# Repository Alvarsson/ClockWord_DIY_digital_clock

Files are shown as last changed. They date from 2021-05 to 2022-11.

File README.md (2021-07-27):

# ClockWork_DIY_digital_clock
Code for homemade digital clock. 

# Effects to add
"Circle" + line in the middle
Fill in/out on number change
"Circle" wave

# Important notes
The KiCad design doesn't have a voltage divider for the TX pin of the ESP8266. If the arduino isn't talking to the ESP8266 properly, make sure that the input voltage to the Arduino isn't too high.

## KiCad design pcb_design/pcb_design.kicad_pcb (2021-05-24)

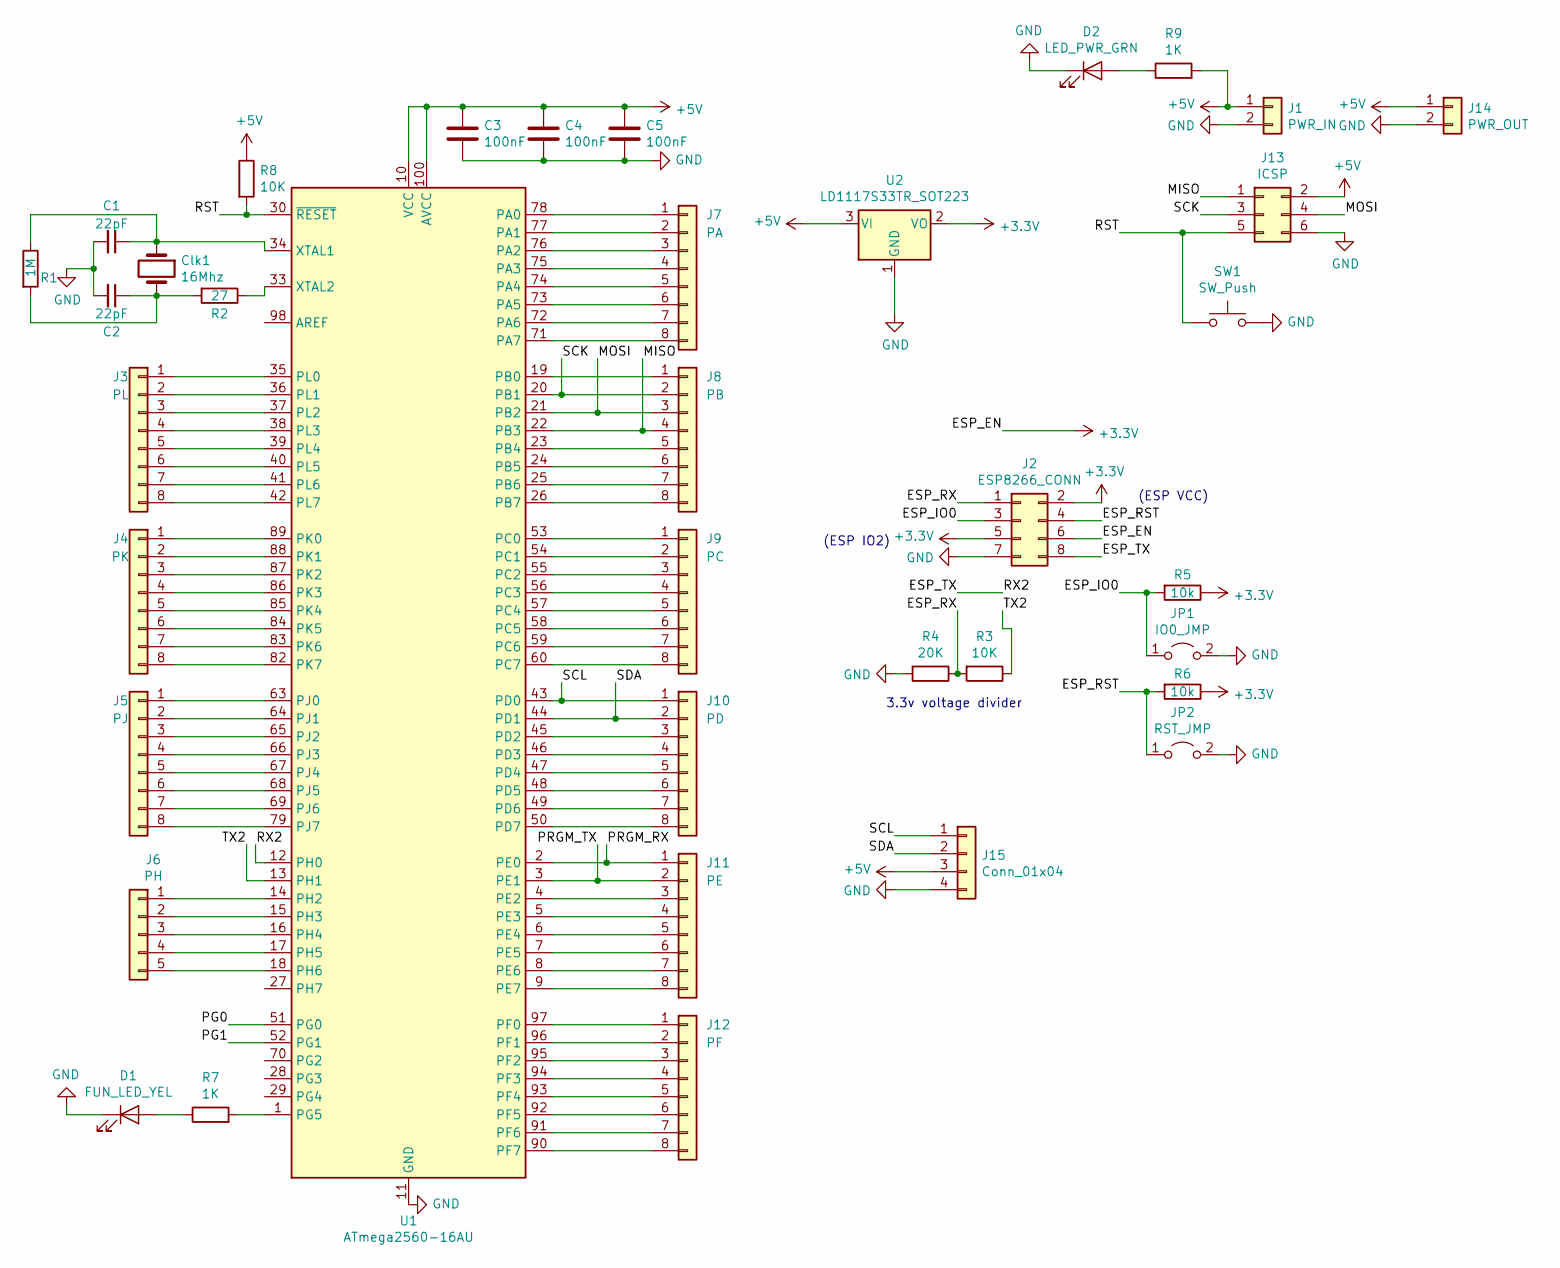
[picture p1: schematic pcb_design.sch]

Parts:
C1, C2: 22pF; C_0603_1608Metric
C3, C4, C5: 100nF; C_0603_1608Metric
Clk1: 16Mhz; Crystal_HC49-4H_Vertical
D1: FUN_LED_YEL; LED_0603_1608Metric
D2: LED_PWR_GRN; LED_0603_1608Metric
J1: PWR_IN; PinHeader_1x02_P2.54mm_Vertical
J2: ESP8266_CONN; PinHeader_2x04_P2.54mm_Vertical
J3: PL; PinHeader_1x08_P2.54mm_Vertical
J4: PK; PinHeader_1x08_P2.54mm_Vertical
J5: PJ; PinHeader_1x08_P2.54mm_Vertical
J6: PH; PinHeader_1x05_P2.54mm_Vertical
J7: PA; PinHeader_1x08_P2.54mm_Vertical
J8: PB; PinHeader_1x08_P2.54mm_Vertical
J9: PC; PinHeader_1x08_P2.54mm_Vertical
J10: PD; PinHeader_1x08_P2.54mm_Vertical
J11: PE; PinHeader_1x08_P2.54mm_Vertical
J12: PF; PinHeader_1x08_P2.54mm_Vertical
J13: ICSP; PinHeader_2x03_P2.54mm_Vertical
J14: PWR_OUT; PinHeader_1x02_P2.54mm_Vertical
J15: Conn_01x04; PinSocket_1x04_P2.54mm_Vertical
JP1: IO0_JMP; PinHeader_1x02_P2.54mm_Vertical
JP2: RST_JMP; PinHeader_1x02_P2.54mm_Vertical
R1: 1M; R_0603_1608Metric
R2: 27; R_0603_1608Metric
R3, R8: 10K; R_0603_1608Metric
R4: 20K; R_0603_1608Metric
R5, R6: 10k; R_0603_1608Metric
R7, R9: 1K; R_0603_1608Metric
SW1: SW_Push; SW_SPST_B3U-1000P
U1: ATmega2560-16AU; TQFP-100_14x14mm_P0.5mm
U2: LD1117S33TR_SOT223; SOT-223-3_TabPin2

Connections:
+3V3: J2.2, J2.5, J2.6, R5.1, R6.1, U2.2 (VO)
+5V: C3.1, C4.1, C5.1, J1.1, J13.2, J14.1, J15.3, R8.1, R9.2, U1.10 (VCC), U1.31 (VCC), U1.61 (VCC), U1.80 (VCC), U1.100 (AVCC), U2.3 (VI)
/ESP_IO0: J2.3, JP1.1 (A), R5.2
/ESP_RST: J2.4, JP2.1 (A), R6.2
/ESP_RX: J2.1, R3.2, R4.1
/ESP_TX: J2.8, U1.12 (PH0)
/MISO: J8.4, J13.1, U1.22 (PB3)
/MOSI: J8.3, J13.4, U1.21 (PB2)
/PG0: U1.51 (PG0)
/PG1: U1.52 (PG1)
/PRGM_RX: J11.1, U1.2 (PE0)
/PRGM_TX: J11.2, U1.3 (PE1)
/RST: J13.5, R8.2, SW1.1, U1.30 (~RESET)
/SCK: J8.2, J13.3, U1.20 (PB1)
/SCL: J10.1, J15.1, U1.43 (PD0)
/SDA: J10.2, J15.2, U1.44 (PD1)
/TX2: R3.1, U1.13 (PH1)
GND: C1.2, C2.2, C3.2, C4.2, C5.2, D1.1 (K), D2.1 (K), J1.2, J2.7, J13.6, J14.2, J15.4, JP1.2 (B), JP2.2 (B), R4.2, SW1.2, U1.11 (GND), U1.32 (GND), U1.62 (GND), U1.81 (GND), U1.99 (GND), U2.1 (GND)
unnamed: C1.1, Clk1.1, R1.1, U1.34 (XTAL1)
unnamed: C2.1, Clk1.2, R1.2, R2.2
unnamed: D1.2 (A), R7.1
unnamed: D2.2 (A), R9.1
unnamed: J3.1, U1.35 (PL0)
unnamed: J3.2, U1.36 (PL1)
unnamed: J3.3, U1.37 (PL2)
unnamed: J3.4, U1.38 (PL3)
unnamed: J3.5, U1.39 (PL4)
unnamed: J3.6, U1.40 (PL5)
unnamed: J3.7, U1.41 (PL6)
unnamed: J3.8, U1.42 (PL7)
unnamed: J4.1, U1.89 (PK0)
unnamed: J4.2, U1.88 (PK1)
unnamed: J4.3, U1.87 (PK2)
unnamed: J4.4, U1.86 (PK3)
unnamed: J4.5, U1.85 (PK4)
unnamed: J4.6, U1.84 (PK5)
unnamed: J4.7, U1.83 (PK6)
unnamed: J4.8, U1.82 (PK7)
unnamed: J5.1, U1.63 (PJ0)
unnamed: J5.2, U1.64 (PJ1)
unnamed: J5.3, U1.65 (PJ2)
unnamed: J5.4, U1.66 (PJ3)
unnamed: J5.5, U1.67 (PJ4)
unnamed: J5.6, U1.68 (PJ5)
unnamed: J5.7, U1.69 (PJ6)
unnamed: J5.8, U1.79 (PJ7)
unnamed: J6.1, U1.14 (PH2)
unnamed: J6.2, U1.15 (PH3)
unnamed: J6.3, U1.16 (PH4)
unnamed: J6.4, U1.17 (PH5)
unnamed: J6.5, U1.18 (PH6)
unnamed: J7.1, U1.78 (PA0)
unnamed: J7.2, U1.77 (PA1)
unnamed: J7.3, U1.76 (PA2)
unnamed: J7.4, U1.75 (PA3)
unnamed: J7.5, U1.74 (PA4)
unnamed: J7.6, U1.73 (PA5)
unnamed: J7.7, U1.72 (PA6)
unnamed: J7.8, U1.71 (PA7)
unnamed: J8.1, U1.19 (PB0)
unnamed: J8.5, U1.23 (PB4)
unnamed: J8.6, U1.24 (PB5)
unnamed: J8.7, U1.25 (PB6)
unnamed: J8.8, U1.26 (PB7)
unnamed: J9.1, U1.53 (PC0)
unnamed: J9.2, U1.54 (PC1)
unnamed: J9.3, U1.55 (PC2)
unnamed: J9.4, U1.56 (PC3)
unnamed: J9.5, U1.57 (PC4)
unnamed: J9.6, U1.58 (PC5)
unnamed: J9.7, U1.59 (PC6)
unnamed: J9.8, U1.60 (PC7)
unnamed: J10.3, U1.45 (PD2)
unnamed: J10.4, U1.46 (PD3)
unnamed: J10.5, U1.47 (PD4)
unnamed: J10.6, U1.48 (PD5)
unnamed: J10.7, U1.49 (PD6)
unnamed: J10.8, U1.50 (PD7)
unnamed: J11.3, U1.4 (PE2)
unnamed: J11.4, U1.5 (PE3)
unnamed: J11.5, U1.6 (PE4)
unnamed: J11.6, U1.7 (PE5)
unnamed: J11.7, U1.8 (PE6)
unnamed: J11.8, U1.9 (PE7)
unnamed: J12.1, U1.97 (PF0)
unnamed: J12.2, U1.96 (PF1)
unnamed: J12.3, U1.95 (PF2)
unnamed: J12.4, U1.94 (PF3)
unnamed: J12.5, U1.93 (PF4)
unnamed: J12.6, U1.92 (PF5)
unnamed: J12.7, U1.91 (PF6)
unnamed: J12.8, U1.90 (PF7)
unnamed: R2.1, U1.33 (XTAL2)
unnamed: R7.2, U1.1 (PG5)

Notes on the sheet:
(ESP VCC)
(ESP IO2)
3.3v voltage divider

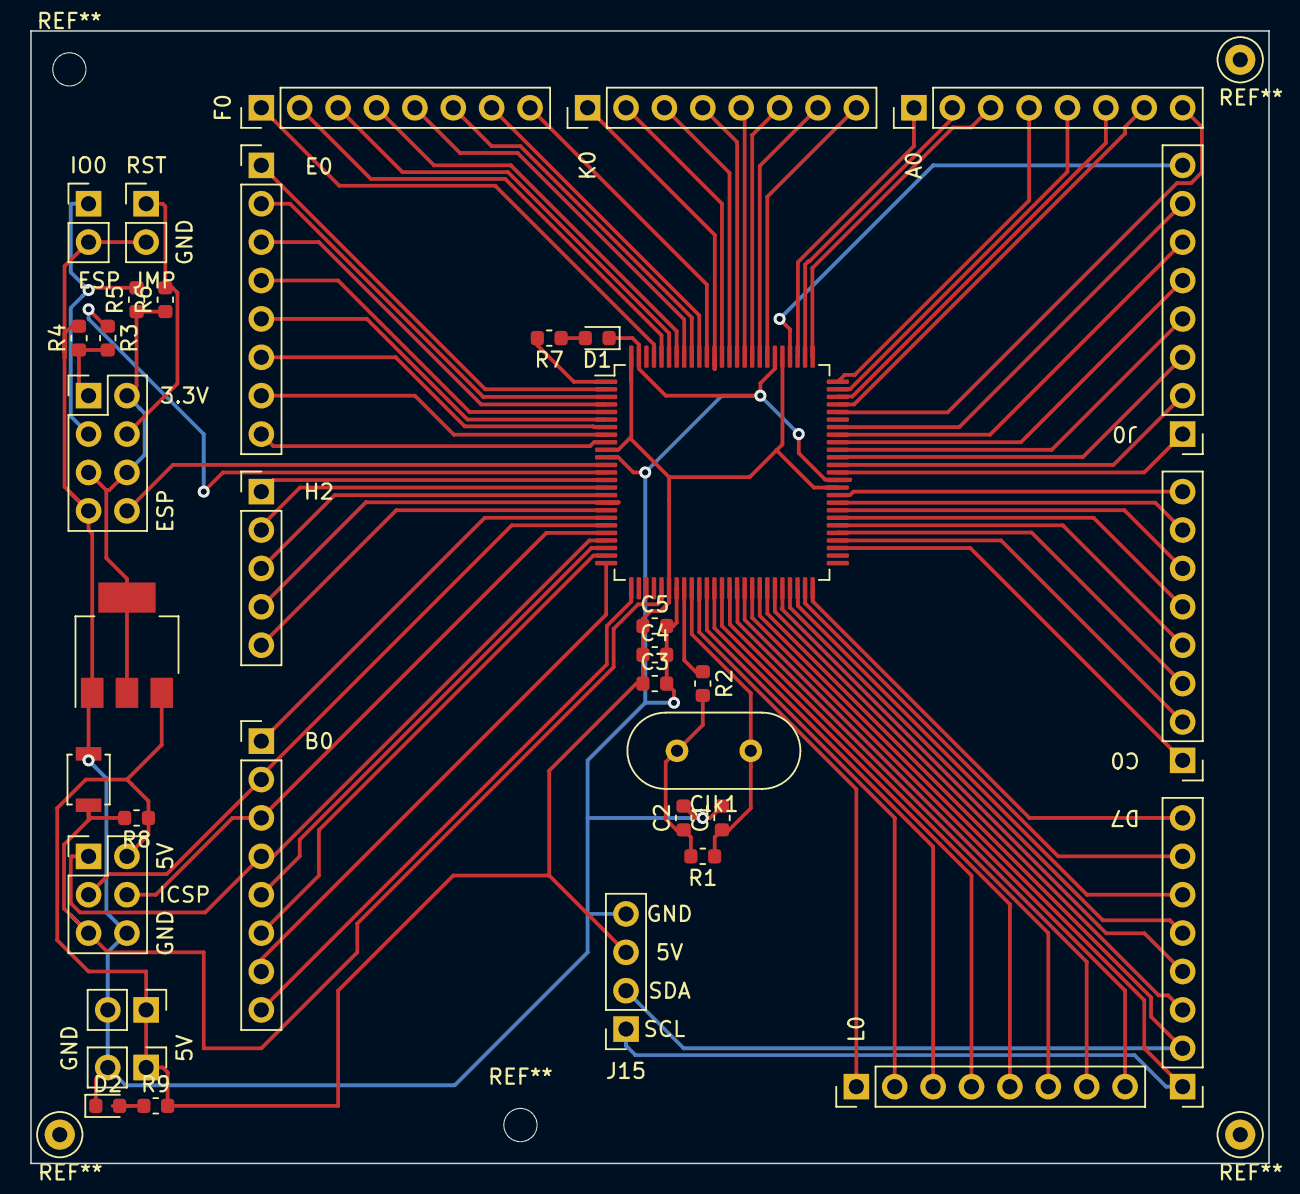
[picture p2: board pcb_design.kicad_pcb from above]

Board: 2 copper layers, 81.9 x 74.9 mm, 37 parts (0 on the bottom side), 92 nets.

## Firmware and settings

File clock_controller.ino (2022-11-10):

#include "animations.h"

#define SW_RX 6
#define SW_TX 7
#define COLOR_COUNT 4

#define BRIGHTNESS 100

CRGB wave_colors[] = {CRGB(0, BRIGHTNESS, 0), CRGB(BRIGHTNESS, 0, 0), CRGB(BRIGHTNESS, BRIGHTNESS, 0), CRGB(BRIGHTNESS, 0, BRIGHTNESS)};
rgb_wave waves[COLOR_COUNT];
clock_t clock;

uint32_t leet_start = 49020;
uint32_t leet_end = 49020 + 60;
uint32_t yes_start = 15600;
uint32_t yes_end = 15600 + 60;
uint32_t current_time_seconds = 10;

uint8_t timer_overflow_count;

// Serial and FastLED also use
// interrupts, so don't use them/call
// functions that use them from this
// interrupt handler
ISR(TIMER1_COMPA_vect) {
  TCNT0 = 0;
  timer_overflow_count++;
  if (timer_overflow_count == 250) {
    clock.dots_on = !clock.dots_on;
    current_time_seconds++;
    timer_overflow_count = 0;
  }
}

void display_time(clock_t *clock, uint32_t seconds) {
  uint32_t days = (seconds / 86400);
  uint32_t hours = (seconds % 86400) / 3600;
  uint32_t minutes = (seconds % 3600) / 60;

  disable_incorrect_segments(&clock->displays[0], numbers[hours / 10]);
  disable_incorrect_segments(&clock->displays[1], numbers[hours % 10]);
  disable_incorrect_segments(&clock->displays[2], numbers[minutes / 10]);
  disable_incorrect_segments(&clock->displays[3], numbers[minutes % 10]);

}

#define TIME_CHARS 8
#define HOURS_MSD_OFFSET 0
#define HOURS_LSD_OFFSET 1
#define MINUTES_MSD_OFFSET 3
#define MINUTES_LSD_OFFSET 4
#define SECONDS_MSD_OFFSET 6
#define SECONDS_LSD_OFFSET 7
void get_time() {
  uint32_t now = current_time_seconds;
  
  Serial3.write("AT+CIPSNTPTIME?\r\n", 18);

  int space_count = 0;
  uint32_t loop_count = 0;
  while (space_count < 3) {
    int input = Serial3.read();
    Serial.write(input);
    if (input == ' ') {
      space_count++;
    }
    loop_count++;
    if (loop_count == 400000) {
      return;
    }
  }

  uint8_t all_str[TIME_CHARS];
  Serial3.readBytes(all_str, TIME_CHARS);

  uint32_t hours = ((all_str[HOURS_MSD_OFFSET] - '0') * 10) + (all_str[HOURS_LSD_OFFSET] - '0');
  uint32_t minutes = ((all_str[MINUTES_MSD_OFFSET] - '0') * 10) + (all_str[MINUTES_LSD_OFFSET] - '0');
  uint32_t seconds = ((all_str[SECONDS_MSD_OFFSET] - '0') * 10) + (all_str[SECONDS_LSD_OFFSET] - '0');

  Serial3.readBytes(all_str, 6);

  current_time_seconds = (hours * 3600) + (minutes * 60) + seconds;

  Serial.print(current_time_seconds);

}

#undef ECHO
#ifdef ECHO
void setup() {
  Serial.begin(115200);
  Serial3.begin(115200);
  Serial.println("Begin!");
}

void loop() {
  while (Serial.available() > 0) {
    uint8_t val = Serial.read();
    Serial3.write(val);
  }
  while (Serial3.available() > 0) {
    uint8_t val = Serial3.read();
    Serial.write(val);
  }
}

#else

void setup() {
  Serial.begin(115200);
  Serial3.begin(115200);  

  // To change time: update the 2nd number (set it to "1,2" or "1,1")
  Serial3.print("AT+CIPSNTPCFG=1,1,\"se.pool.ntp.org\"\r\n");

  uint8_t read_bytes = 0;
  
  while (read_bytes < 4) {
    int value = Serial3.read();
    if (value > 0) {
      read_bytes++;
    }
  }


  FastLED.addLeds<NEOPIXEL, DISPLAY0_PIN>(clock.displays[0].leds, LEDS_PER_DISPLAY);
  FastLED.addLeds<NEOPIXEL, DISPLAY1_PIN>(clock.displays[1].leds, LEDS_PER_DISPLAY);
  FastLED.addLeds<NEOPIXEL, DISPLAY2_PIN>(clock.displays[2].leds, LEDS_PER_DISPLAY);
  FastLED.addLeds<NEOPIXEL, DISPLAY3_PIN>(clock.displays[3].leds, LEDS_PER_DISPLAY);
  FastLED.addLeds<NEOPIXEL, DOT_UP_PIN>(clock.dots, LEDS_PER_DOT);
  FastLED.addLeds<NEOPIXEL, DOT_DOWN_PIN>(clock.dots + LEDS_PER_DOT, LEDS_PER_DOT);
  FastLED.show();

  OCR1A = 200;
  TCCR1B = (1 << CS12);
  TIMSK1 = (1 << OCIE1A);

  init_waves(waves, wave_colors, COLOR_COUNT, LEDS_PER_SEGMENT * 12);
}

uint8_t direction = 0;
#define STEP 5
#define BRIGHTNESS_MIN 10
#define BRIGHTNESS_MAX 255
uint8_t brightness = BRIGHTNESS_MIN;

void loop() {
  while (Serial3.available()) Serial3.read();
  _delay_ms(10);
  if (current_time_seconds % 30 == 0) {
    get_time();
  }

  uint8_t is_first_minute = 0;
  uint16_t seconds_into_hour = current_time_seconds % 3600;
  int32_t data = current_time_seconds - 43200;
  if (data < 0) {
    data *= -1;
  }
  data = 102 - ((102 * data) / 43200);
  if (seconds_into_hour >= 0 && seconds_into_hour < 60) {
    is_first_minute = 1;
  }
  
  if (direction == 0){
    brightness += STEP;
  } else {
    brightness -= STEP;
  }
  if (brightness == BRIGHTNESS_MAX || brightness == BRIGHTNESS_MIN) {
    direction = !direction;
  }

  if (current_time_seconds >= 0 && current_time_seconds < 60) {
    set_clock_color(&clock, CRGB(brightness, 0, 0));
  } else {
    if (current_time_seconds >= yes_start && current_time_seconds < yes_end) {
      set_clock_color(&clock, CRGB(0, brightness, 0));
    } else if ((current_time_seconds >= leet_start && current_time_seconds < leet_end) || is_first_minute){
      for (uint8_t i = 0; i < COLOR_COUNT; i++){
        display_rgb_wave(&clock, waves + i, 3);     
      }
    } else {
      set_clock_color(&clock, CRGB(50, data, 0));    
    }
    display_time(&clock, current_time_seconds);
  }
  FastLED.show();

}
#endif

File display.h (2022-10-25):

#ifndef DISPLAY_H
#define DISPLAY_H

#include <FastLED.h>

#define SEGMENTS_PER_DISPLAY 7
#define LEDS_PER_SEGMENT 10
#define LEDS_PER_DOT 2
#define LEDS_PER_DISPLAY (LEDS_PER_SEGMENT * SEGMENTS_PER_DISPLAY)
#define COLUMNS_PER_DISPLAY (LEDS_PER_SEGMENT + 2)



#define DISPLAY0_PIN 58 // C0
#define DISPLAY1_PIN 56 // C1
#define DISPLAY2_PIN 55 // C2
#define DISPLAY3_PIN 54 // C3

typedef struct {
  CRGB leds[LEDS_PER_DISPLAY];
} display_t;

extern const char *all;
extern const char *zero;
extern const char *one;
extern const char *two;
extern const char *three;
extern const char *four;
extern const char *five;
extern const char *six;
extern const char *seven;
extern const char *eight;
extern const char *nine;
extern const char *numbers[10];

void set_segments(display_t *display, const char *segments, CRGB color);
void disable_incorrect_segments(display_t *display, const char *number);
void set_inverted_segments(display_t *display, const char *segments, CRGB color);
void clear_display(display_t *display);
void set_display_color(display_t *display, CRGB color);
uint8_t is_full_column(uint8_t column);
uint8_t get_led_at_xy(display_t *display, uint8_t horizontal, uint8_t vertical, CRGB **led);
void set_column(display_t *display, uint8_t column, CRGB color);
#endif

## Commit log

2021-04-04 Fix functions a bit more
    [clock_controller.ino]
2021-04-04 Move around and fix names
    [clock_controller.ino]
2021-04-06 Add kicad files
    [pcb_design.kicad_pcb, pcb_design.sch]
2021-04-06 Damn this is cool
    [pcb_design.sch]
2021-04-07 Add small thingoes
    [pcb_design.sch]
2021-04-07 Move and stuff
    [atmega8u2.sch, pcb_design.sch]
2021-04-08 Add ISP header and bit more of USB thingo
    [atmega8u2.sch, pcb_design.sch]
2021-04-08 Move around
    [atmega8u2.sch, pcb_design.sch]
2021-04-09 Make PCB design
    [atmega8u2.sch, pcb_design.kicad_pcb, pcb_design.sch]
2021-04-10 Almost done?
    [atmega8u2.sch, pcb_design.kicad_pcb, pcb_design.sch]
2021-04-10 Small changes
    [pcb_design.sch]
2021-04-16 Only 1 error message!
    [clock_controller.ino]
2021-04-17 Add DS3231 RTC header
    [pcb_design.kicad_pcb, pcb_design.sch]
2021-04-17 Add lineout to PCB design
    [pcb_design.kicad_pcb]
2021-04-17 Add mounting holes
    [pcb_design.kicad_pcb]
2021-05-24 0603EU -> 0603US
    [pcb_design.kicad_pcb, pcb_design.sch]
2021-07-25 Use interrupt instead of timeout More stuff
2021-07-25 Update for atmega2560 board
2021-07-31 Add some more special effects
    Try to add a watchdog for reading the time so it's less likely to get stuck
    [clock_controller.ino]
2022-10-25 New pin numbers
2022-10-25 Update to new, soldered pins
    Change timezone
